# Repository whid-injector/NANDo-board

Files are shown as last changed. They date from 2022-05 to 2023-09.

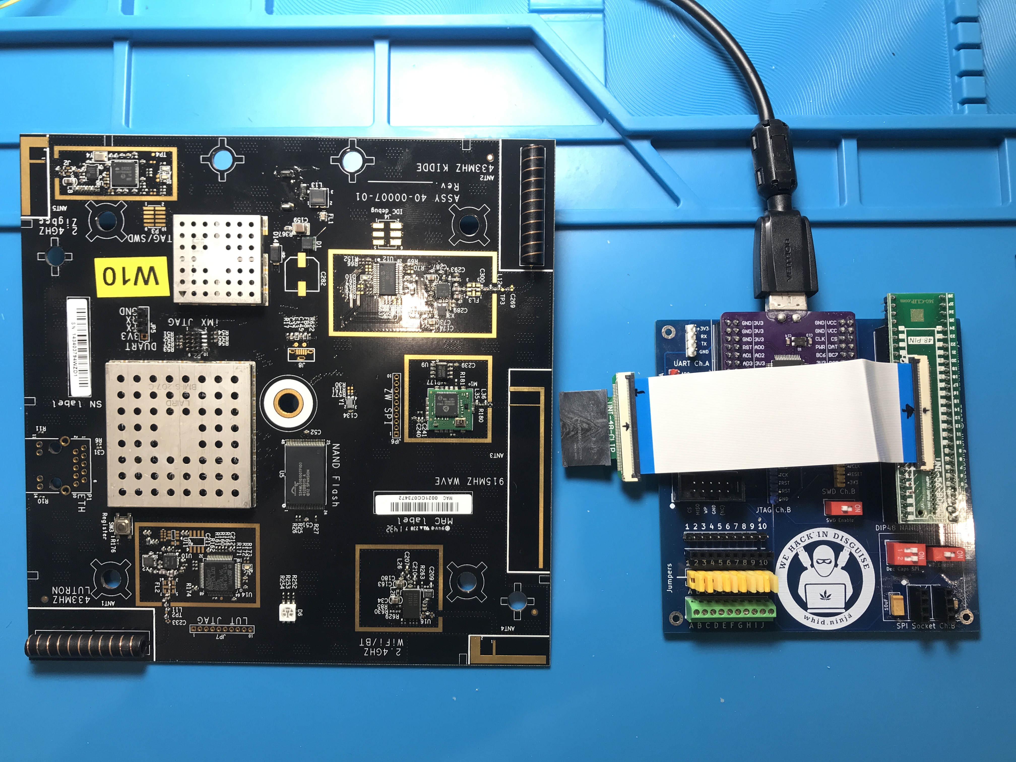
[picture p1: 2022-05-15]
Images/NAND_Dump.jpg

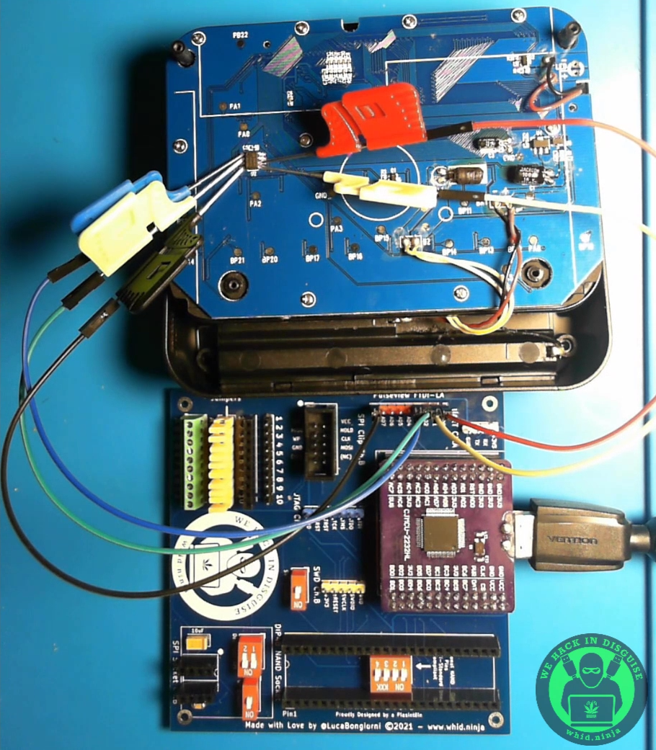
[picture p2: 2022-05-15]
Images/Pulseview_Logic_Analyzer_SPI_Sniffing.png

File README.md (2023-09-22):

# NANDo-Board
A Multipurpose Breakout for the FT2232HL to easily conduct Hardware Security tests and Hack (I)IoT devices! 

<a href='https://ko-fi.com/X7X6L82L' target='_blank'>Buy Me a Coffee at ko-fi.com</a>



## WHID's Trainings
The 𝙊𝙛𝙛𝙚𝙣𝙨𝙞𝙫𝙚 𝙃𝙖𝙧𝙙𝙬𝙖𝙧𝙚 𝙃𝙖𝙘𝙠𝙞𝙣𝙜 𝙏𝙧𝙖𝙞𝙣𝙞𝙣𝙜 is a Self-Paced training including Videos, a printed Workbook and a cool Hardware Hackit Kit. And... you get everything shipped home Worldwide! 🌍🔥😎<br>
For more info... ➡ https://www.whid.ninja/store <br><br>

WHID's Trainings (https://www.youtube.com/watch?v=zbUuBZJIHkE)

# Bill-of-Materials
Please check the BOM.txt for the components needed. Most likely (except the R470OHM 2010) you may have all you need already.<br>
Of course, you still need to purchase a part the FT2232HL CJMCU (e.g. https://s.click.aliexpress.com/e/_DeK6Oor )

# Tips:<br>
- This breakout is designed for the FT2232HL CJMCU board (e.g. https://s.click.aliexpress.com/e/_DeK6Oor )<br>
- Pull-up Resistor is 470Ohm.<br>
- Screws to hold the PCB to the 3D-printed case are 2x6mm.<br>
- BE SURE to mount the FT2232HL with the FTDI chipset FACING UP!!!

## UART (Channel A)
Command to run the UART console feature:
Configure minicom/putty/whatever-terminal-you-are-used-to (e.g.<br> ```screen /dev/ttyUSB0 115200```<br>
```screen -L /dev/ttyUSB0 115200```<br>
```screen -L -Logfile UART.log /dev/ttyUSB0 115200```)

## JTAG (Channel B)
Command to run the JTAG debugging feature:<br>
```sudo openocd -f NANDo-Board_JTAG_OpenOCD.cfg  -f target_device.cfg```

## SWD (Channel B) (this works on openocd v.0.11 but NOT on v.0.10!!!)
Command to run the SWD debugging feature (remember to move the SWD Enable switch on the PCB before using this feature!):

```cd openocd-v.0.11```<br>
```./openocd -s /opt/openocd/share/openocd/scripts/ -f /home/FOO/Desktop/NANDo-Board/OpenOCD_Configs/NANDo-Board_SWD_OpenOCD.cfg -f target_device.cfg```<br>

## SPI Dumping (Channel B)
Command to run the SPI dumping feature:<br>
```flashrom -p ft2232_spi:type=2232H,port=B -r firmware.bin```

In case you need also to write a SPI flash... please do enable the WRITE PROTECT (WP) Jumper on the PCB (i.e. SPI WP Enable).

## NAND Dumping
Dump Raw Image:<br>
```yand_cli.py -r -f nand_raw_dump_withOOB.bin```

Remove OOB Data:<br>
```python Nand-dump-tool.py -i nand_raw_dump_withOOB.bin  -o nand_raw_dump_cleaned.bin --page-size 2048 --oob-size 64 --layout separate```<br>
OR <br>
```python Nand-dump-tool.py -i nand_raw_dump_withOOB.bin --layout=guess -I <ID-CODE-HERE> -o nand_raw_dump_cleaned.bin```<br>

## Logic Analyzer with Pulseview
The strip pins AD0-AD7 labeled "Pulseview FTDI-LA" can be used as low-frequency Logic Analyzer Channels with Pulseview/Sigrok tool.
Here the configuration 

![image](https://raw.githubusercontent.com/whid-injector/NANDo-board/master/Images/NANDo-board_Pulseview_Configuration.png)

## Multipurpose Pin Headers/Sockets
On the lower part of NANDo-Board's PCB there are some pin headers/sockets that are not connected with the FT2232HL. They are there just in case you need to mess-up with many flying-wires and you want to keep all connections clean and in order like with an usual breadboard, but with screwdown terminal blocks & co.

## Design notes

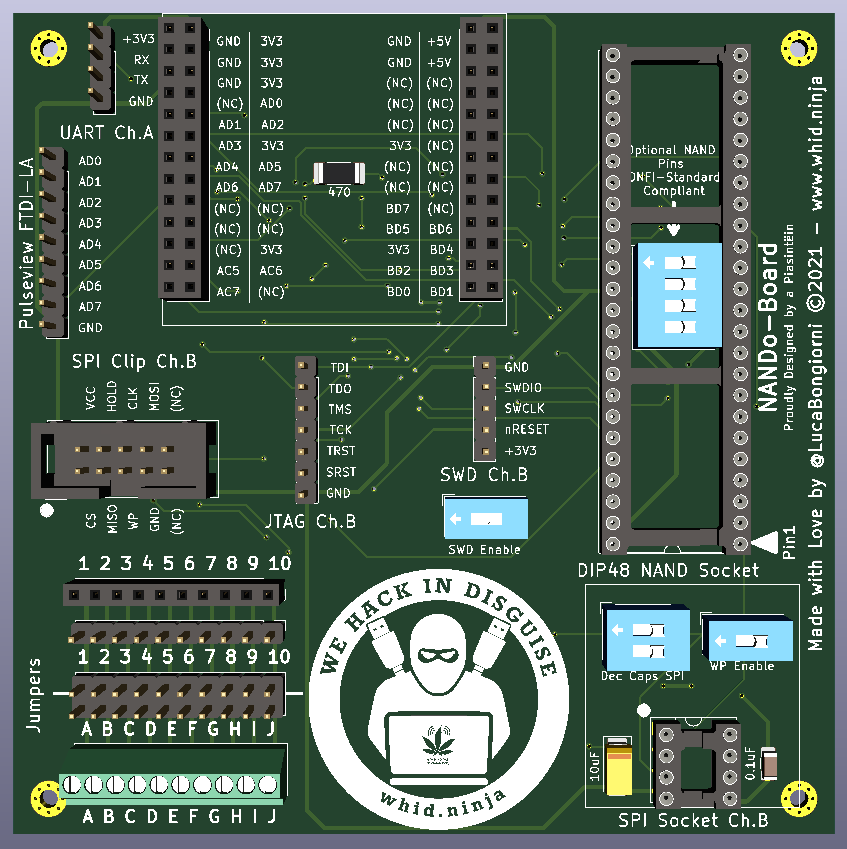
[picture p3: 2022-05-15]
Images/NANDO_Front_PCB.PNG

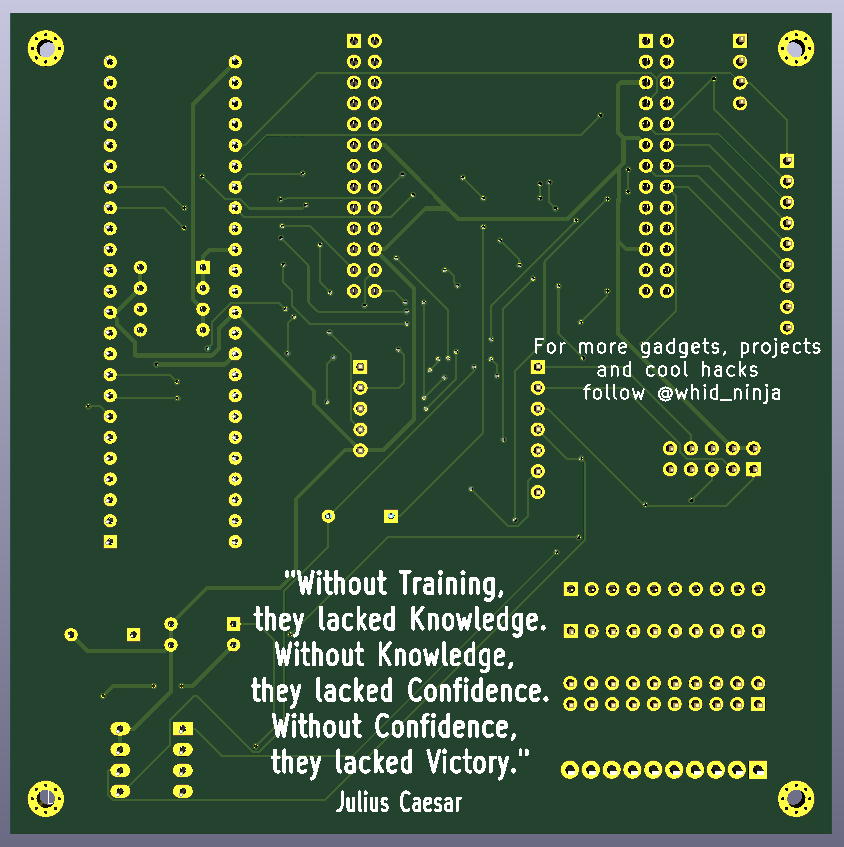
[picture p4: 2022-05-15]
Images/NANDO_Back_PCB.PNG

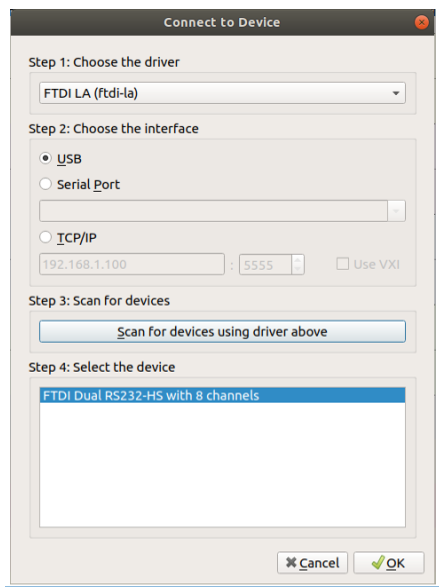
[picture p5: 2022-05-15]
Images/NANDo-board_Pulseview_Configuration.png

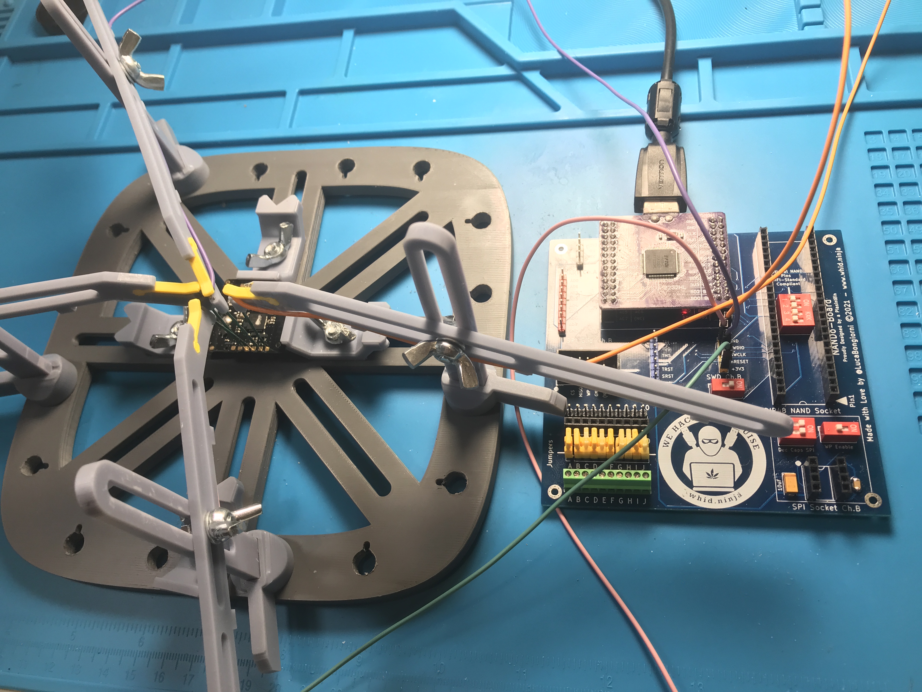
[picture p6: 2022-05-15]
Images/SWD.jpg

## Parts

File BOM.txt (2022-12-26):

- 4-Pin 2.54mm Pin-Header [x1]  [e.g. https://www.aliexpress.com/item/32864438850.html]
- 5-Pin 2.54mm Pin-Header [x1]
- 7-Pin 2.54mm Pin-Header [x1]
- 9-Pin 2.54mm Pin-Header [x1]
- 10-Pin 2.54mm Pin-Header [x2]

- 2x5-Pin 2.54mm Pin-Header [x1] [e.g. https://www.aliexpress.com/item/32959110632.html]
- 2x10-Pin 2.54mm Pin-Header [x1]

- 4-Pin 2.54mm Pin-Socket [x2] [e.g. https://www.aliexpress.com/item/32838874466.html] For the DIP-8 socket
- 10-Pin 2.54mm Pin-Socket [x1]
- 12-Pin 2.54mm Pin-Socket [x4] or 24-Pin 2.54mm Pin-Socket [x2][E.G. https://www.aliexpress.com/item/1005001418544370.html] For the NAND DIP-48 socket

- 2x13-Pin 2.54mm Pin-SOCKET [x2] [E.G. https://www.aliexpress.com/item/1005001781173114.html]

- 1-Pin 2.54mm Dip Switch [x2] [e.g. https://www.aliexpress.com/item/32879944485.html ]

- 2-Pin 2.54mm Dip Switch [x1] [e.g. https://www.aliexpress.com/item/32879944485.html ]

- 4-Pin 2.54mm Dip Switch [x1] [e.g. https://www.aliexpress.com/item/32879944485.html ]

- Capacitor Tantalum 10 uF 6032 (2412/2312 inch) [x1] [e.g T491C106K016AT https://www.tme.eu/lt/en/details/t491c106k016at/smd-tantalum-capacitors/kemet/]

- Capacitor Ceramic 100nF 100V 1206 [x1] [e.g. CL31B104KCFNNNE https://www.tme.eu/lt/en/details/cl31b104kcfnnne/1206-mlcc-smd-capacitors/samsung/ ]

- Jumper with Long Handle [x10] [e.g. https://www.aliexpress.com/item/33016645429.html]

- Resistor 470 Ohm 2010 [x1] [e.g. CQ2010-470R-1%  https://www.tme.eu/lt/en/details/cq2010-470r-1%25/smd-resistors/royal-ohm/cq1007f4700t4e/ ] or [e.g. https://www.aliexpress.com/item/32996302793.html]

- Screws with flat head 2x6mm [x4] [e.g. https://www.aliexpress.com/item/32958878628.html]

- 10-Pin 2.54mm Terminal Block [x1] [e.g. https://www.aliexpress.com/item/33047143170.html]

- Socket SOP-8 to DIP [x1] [e.g. https://www.aliexpress.com/item/32827349954.html]

- Socket SOP-16 to DIP [x1] [e.g. https://www.aliexpress.com/item/32827349954.html]

- Clip SOP8 [x1] [e.g. https://www.aliexpress.com/item/32834585643.html]

- FT2232HL CJMCU [x1] [e.g. https://www.aliexpress.com/item/4001099643640.html]

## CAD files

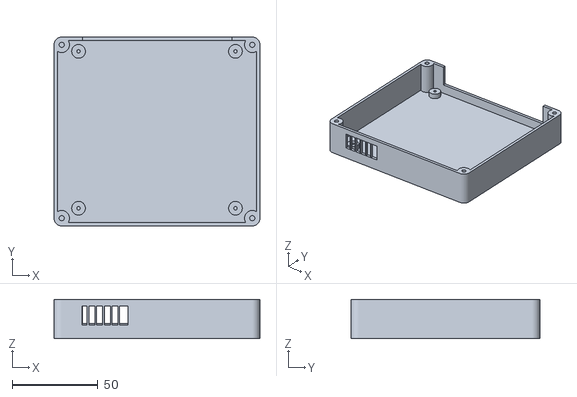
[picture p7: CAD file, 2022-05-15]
3D_Case/NANDo_Board_v.0.2.stl
120.0 x 110.0 x 23.0

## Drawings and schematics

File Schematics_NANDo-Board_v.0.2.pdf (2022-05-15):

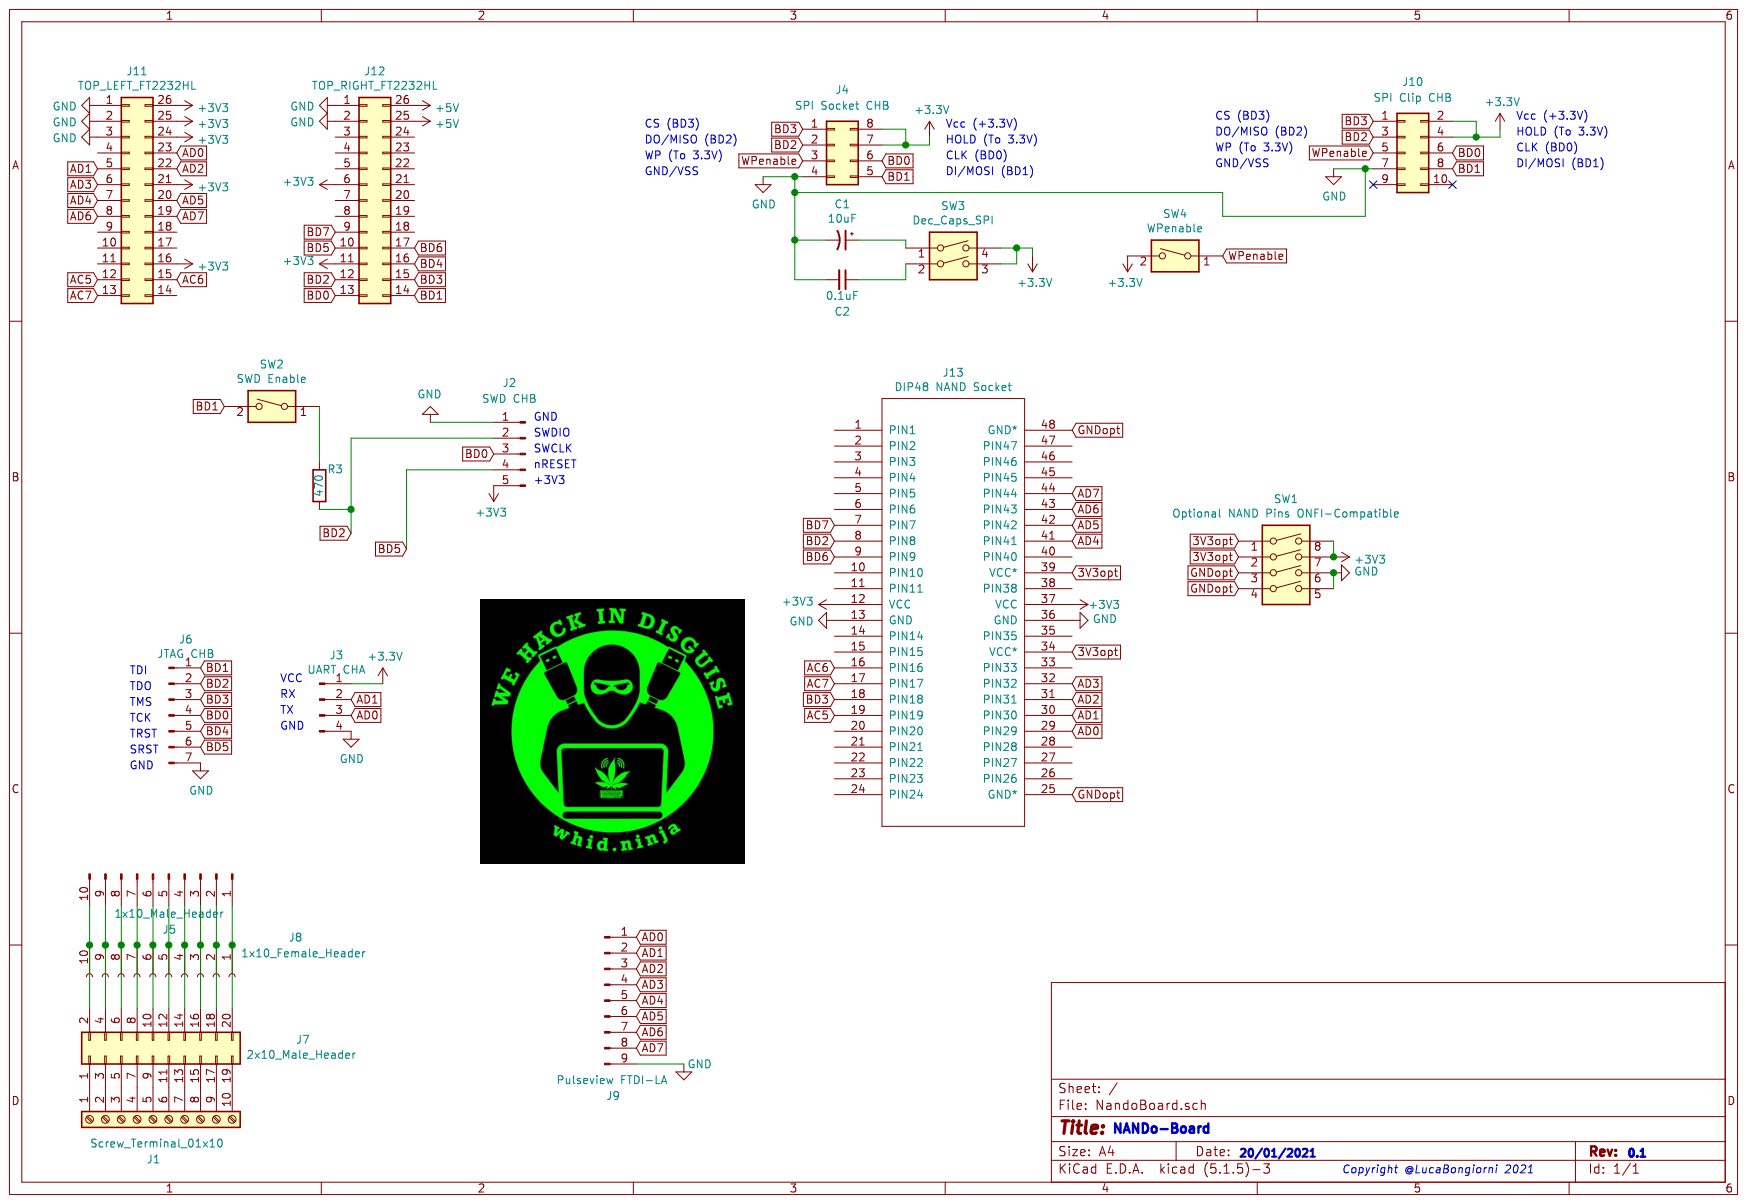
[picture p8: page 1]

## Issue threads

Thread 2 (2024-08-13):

I need help of dump nand

DRCRecoveryData, 2024-08-13:
Hi,

Can i dump nand from sandisk sdcard have config?

```
// Chip
Company      Toshiba
Name         BGA-152 05549 064G
ID code      45 3e 99 b3

// Structure
Bus          8
Banks        1 x 64 GB
Page         18336
Block        0xd6e000
Blocks       0x2000

// Read
Cmd          WL
Col          2
Row          3
DDR          false

// Timings
RE_Up        2
RE_Down      2

// Special
Power
Retry        Sandisk v3
Skip_Mask_1  0xffffffff
Skip_Page_1  0xffffffff
Skip_Mask_2  0xffffffff
Skip_Page_2  0xffffffff
Join CE      1-3
```
